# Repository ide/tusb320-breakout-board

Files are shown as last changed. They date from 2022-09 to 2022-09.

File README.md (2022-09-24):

# TUSB320 Breakout Board

This PCB is a breakout board for the Texas Instruments TUSB320 chip and a USB-C connector (16+8 dummy pins).

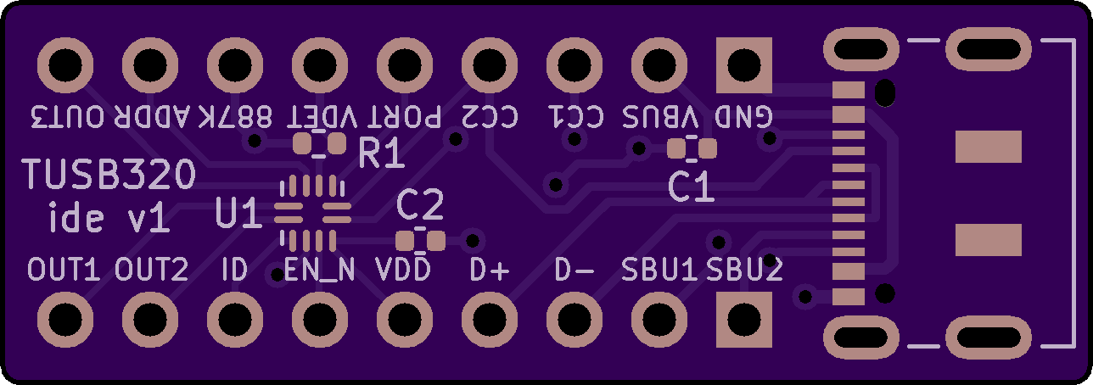
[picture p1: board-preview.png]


## Features

- Headers for each pin of the TUSB320 chip and USB-C connector
- Built-in connections between the USB-C connector's CC1 and CC2 pins and the TUSB320 chip's respective CC1 and CC2 pins
- Pads for smoothing capacitors connected to voltage sources, namely VBUS and VDD. Smoothing capacitors are typically optional and you can leave them off (do not short to ground!) but filtering noise is a good practice.
- A pad for the 887K ohm resistor between the TUSB320 chip's VBUS_DET pin and the USB-C connector's VBUS pin. Note: VBUS_DET and VBUS are not connected by default.
- A jumper pad to connect VBUS_DET to VBUS with an 887K ohm resistor in between. You can either bridge the pads or use a 0 ohm resistor.

## Ordering

TBA

## BOM
| Reference | Part description | Size | Example part # |
|---|---|---|---|
| R1 | 887K ohm resistor | 0402 | [ERJ-2RKF8873X](https://www.digikey.com/en/products/detail/panasonic-electronic-components/ERJ-2RKF8873X/192503) |
| R2 | 0 ohm resistor (optional) | 0402 | [ERJ-2GE0R00X](https://www.digikey.com/en/products/detail/panasonic-electronic-components/ERJ-2GE0R00X/146727) |
| C1 | 1μF 35V capacitor | 0402 | [GRM155R6YA105KE11D](https://www.digikey.com/en/products/detail/murata-electronics/GRM155R6YA105KE11D/4905162) |
| C2 | 0.1μF 5V capacitor | 0402 | [04025C104KAT2A](https://www.digikey.com/en/products/detail/kyocera-avx/04025C104KAT2A/6564238) |
| J1 | USB-C connector (16+8 dummy pins) | Surface mount, right angle, through hole | [DX07S016JA1R1500](https://www.digikey.com/en/products/detail/jae-electronics/DX07S016JA1R1500/11585731) |
| J2, J3 | 1x9 male through hole headers | | [PRPC009SAAN-RC](https://www.digikey.com/en/products/detail/sullins-connector-solutions/PRPC009SAAN-RC/2775245)  |
| U1 | TUSB320, TUSB320LI, TUSB320LAI | 12-X2QFN | [TUSB320LAIRWBR](https://www.digikey.com/en/products/detail/texas-instruments/TUSB320LAIRWBR/5722618) |

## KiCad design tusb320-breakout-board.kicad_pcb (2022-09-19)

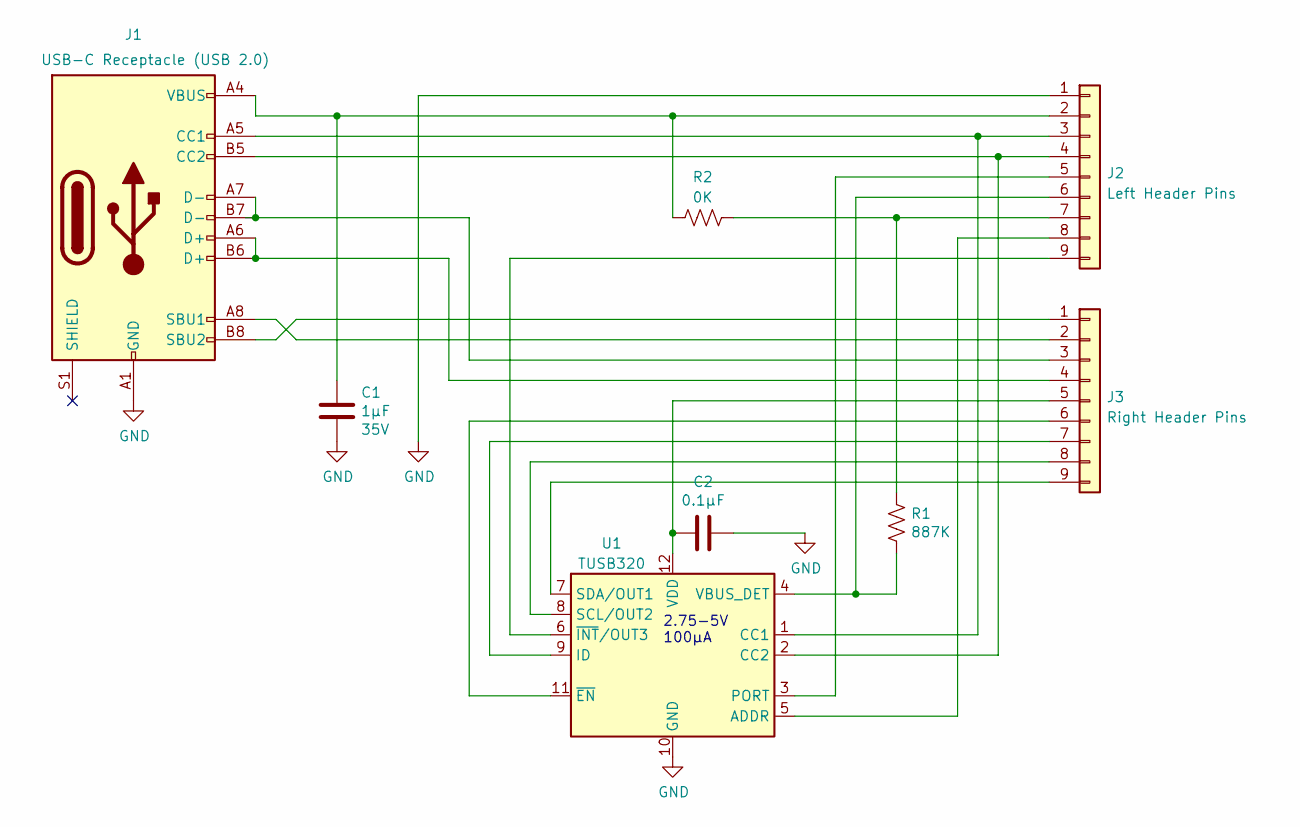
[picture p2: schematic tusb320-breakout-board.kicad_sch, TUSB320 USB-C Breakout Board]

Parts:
C1: 1μF; C_0402_1005Metric; Voltage 35V
C2: 0.1μF; C_0402_1005Metric
J1: USB-C Receptacle (USB 2.0); USB_C_Receptacle_JAE_DX07S016JA1R1500
J2: Left Header Pins; PinHeader_1x09_P2.54mm_Vertical
J3: Right Header Pins; PinHeader_1x09_P2.54mm_Vertical
R1: 887K; R_0402_1005Metric
R2: 0K; R_0402_1005Metric
U1: TUSB320; Texas_X2QFN-12_1.6x1.6mm_P0.4mm

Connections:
GND: C1.1, C2.1, J1.A1 (GND), J1.A12 (GND), J1.B1 (GND), J1.B12 (GND), J2.1, U1.10 (GND)
unnamed: C1.2, J1.A4 (VBUS), J1.A9 (VBUS), J1.B4 (VBUS), J1.B9 (VBUS), J2.2, R2.1
unnamed: C2.2, J3.5, U1.12 (VDD)
unnamed: J1.A5 (CC1), J2.3, U1.1 (CC1)
unnamed: J1.A6 (D+), J1.B6 (D+), J3.4
unnamed: J1.A7 (D-), J1.B7 (D-), J3.3
unnamed: J1.A8 (SBU1), J3.2
unnamed: J1.B5 (CC2), J2.4, U1.2 (CC2)
unnamed: J1.B8 (SBU2), J3.1
unnamed: J2.5, U1.3 (PORT)
unnamed: J2.6, R1.2, U1.4 (VBUS_DET)
unnamed: J2.7, R1.1, R2.2
unnamed: J2.8, U1.5 (ADDR)
unnamed: J2.9, U1.6 (~INT/OUT3)
unnamed: J3.6, U1.11 (~EN)
unnamed: J3.7, U1.9 (ID)
unnamed: J3.8, U1.8 (SCL/OUT2)
unnamed: J3.9, U1.7 (SDA/OUT1)

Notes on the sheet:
2.75-5V 100μA

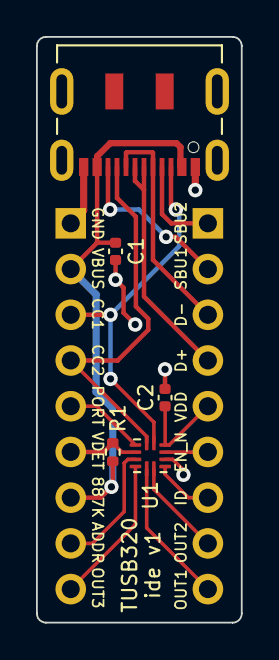
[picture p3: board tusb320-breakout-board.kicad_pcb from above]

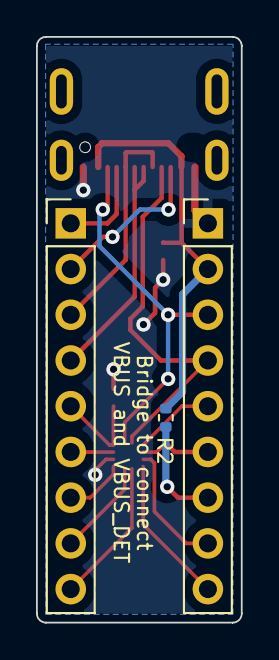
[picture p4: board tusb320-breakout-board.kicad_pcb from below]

Board: 2 copper layers, 11.4 x 32.5 mm, 8 parts (3 on the bottom side), 18 nets.

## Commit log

2022-09-19 Add v1 draft of PCB
    [tusb320-breakout-board.kicad_pcb, tusb320-breakout-board.kicad_sch]
2022-09-19 Add plotted Gerbers
    [tusb320-breakout-board-B_Cu.gbl, tusb320-breakout-board-B_Silkscreen.gbo, tusb320-breakout-board-Edge_Cuts.gm1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]
2022-09-19 Add jumper to connect VBUS to VBUS_DET
    [tusb320-breakout-board.kicad_pcb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]
2022-09-24 [readme] Add board preview
